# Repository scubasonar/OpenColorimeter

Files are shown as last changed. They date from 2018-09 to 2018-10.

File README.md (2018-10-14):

# OpenColorimeter
Open source colorimeter project by Matthew Valancy for California State University Monterey Bay Capstone.

Hardware and software for measuring light passing through a sample vial.

*Mechanical design in FreeCAD v0.17
*Electrical design in KiCAD 5.0.0
*Software written with Arduino IDE 1.8.7

### See Wiki for more information.

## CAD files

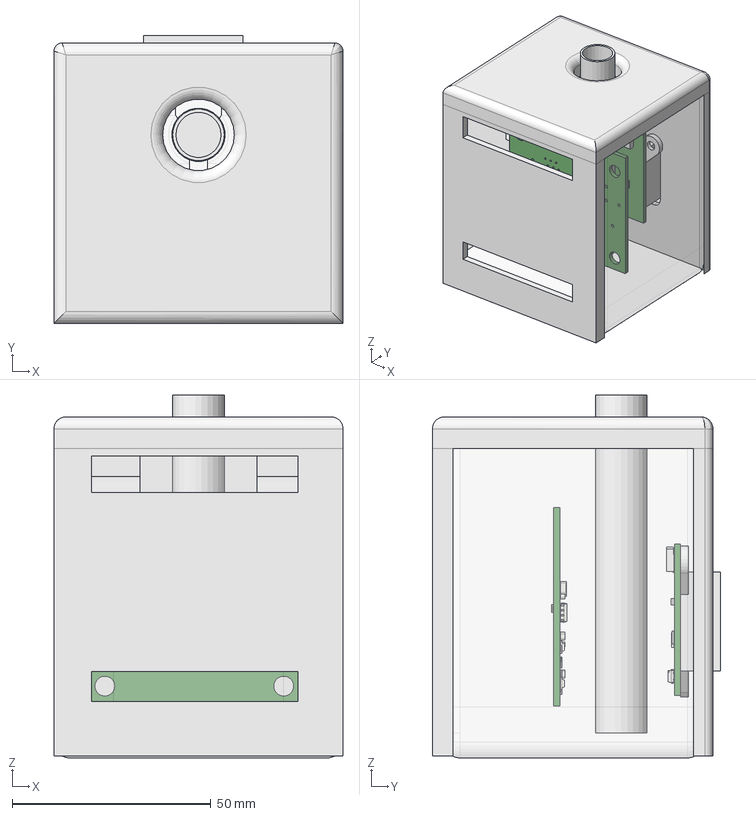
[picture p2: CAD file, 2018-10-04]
Mechanical/Colorimeter.fcstd
72.7 x 72.5 x 91.3 mm
API_Test_Tube_5mlMarked
Housing_Main
ATS-CPX-137-C1-R0_FUSED
Housing_Cover

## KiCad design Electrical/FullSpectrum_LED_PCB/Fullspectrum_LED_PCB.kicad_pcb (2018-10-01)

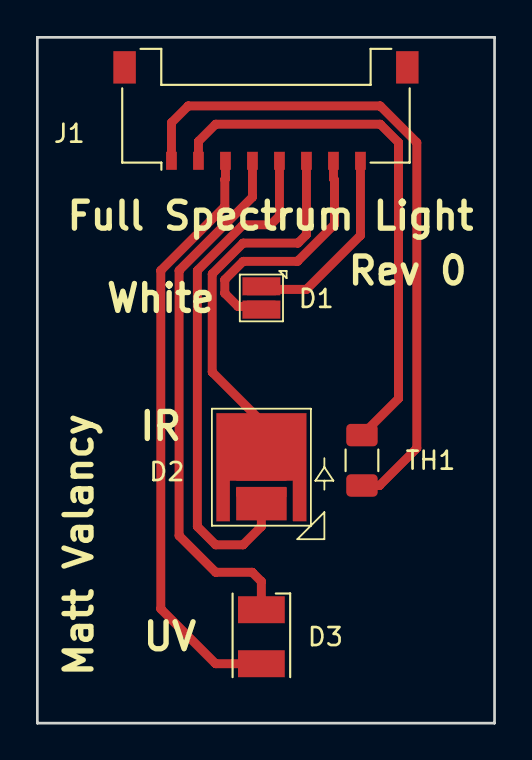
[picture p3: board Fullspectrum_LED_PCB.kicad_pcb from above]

Board: 2 copper layers, 25.4 x 38.1 mm, 5 parts (0 on the bottom side), 8 nets.

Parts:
D1: White_LED; LED_Cree_XQ-E
D2: IR_LED; LED_Oslon_SFH_4735
D3: UV_LED; LED_PLCC-2
J1: Conn_01x08_Male; Molex_Pico-Lock_504050-0891_1x08-1MP_P1.50mm_Horizontal
TH1: Thermistor_NTC; R_1206_3216Metric

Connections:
unnamed: D1.1, J1.8
unnamed: D1.2, J1.7
unnamed: D2.1, J1.6
unnamed: D2.2, J1.5
unnamed: D3.1, J1.4
unnamed: D3.2, J1.3
unnamed: J1.1, TH1.1
unnamed: J1.2, TH1.2

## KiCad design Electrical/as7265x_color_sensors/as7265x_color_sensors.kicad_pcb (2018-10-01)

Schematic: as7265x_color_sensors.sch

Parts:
C1, C2, C3: 100nF; C_0805_2012Metric
C4, C5, C6: 10uF; C_0805_2012Metric
C7: 1uF; C_0805_2012Metric
D1, D2, D3, D4, D5, D6: LED_Small; LED_1206_3216Metric
F1, F2: Polyfuse; C_1206_3216Metric
J1: Conn_01x06_Male; Harwin_M20-89006xx_1x06_P2.54mm_Horizontal
J2, J3: RJ12; RJ12_Amphenol_54601
R1, R2, R3, R4, R5, R6: R_Small; R_0805_2012Metric
R7: 10k; R_0805_2012Metric
R8: DNP; R_0805_2012Metric
R9: 0R; R_0805_2012Metric
R10, R11, R12, R13: 10K; R_0805_2012Metric
TP1, TP2, TP3, TP4, TP5, TP6, TP8, TP9, TP10, TP11, TP12, TP13, TP14, TP15, TP17: TestPoint; Pin_D1.0mm_L10.0mm_LooseFit
TVS1, TVS2, TVS3: SP3012-06UTG; uDFN-14_3.5x1.35x0.5mm
U1: AS72651; LGA-20_4.5mm_4.7mm_2.5mm
U2: AS72652; LGA-20_4.5mm_4.7mm_2.5mm
U3: AS72653; LGA-20_4.5mm_4.7mm_2.5mm
U4: AT25SF041; SOIC-8_3.9x4.9mm_P1.27mm

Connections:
+3V3: C1.1, C2.1, C3.1, C4.1, C5.1, C6.1, C7.1, F1.1, F2.1, J1.4, R1.2, R2.2, R3.2, R4.2, R5.2, R6.2, R7.1, R8.2, TP1.1, TP14.1, TVS1.13, TVS2.13, TVS3.9, U1.14, U1.17, U2.14, U2.17, U3.14, U3.17, U4.3 (~WP), U4.7 (~HOLD), U4.8 (VCC)
/CTS: J1.5, TP15.1, TVS3.8
/DTR: J1.1, TP11.1, TVS3.13
/LED1: D1.1, J3.2, TVS2.8, U1.18
/LED2: D2.1, J3.3, TVS2.9, U1.15
/LED3: D3.1, J3.4, TVS2.11, U2.18
/LED4: D4.1, J3.5, TVS2.12, U2.15
/LED5: D5.1, J2.2, TVS1.8, U3.18
/LED6: D6.1, J2.3, TVS1.9, U3.15
/RXI: J1.3, J2.4, TP13.1, TVS1.11, TVS3.11, U1.11
/TXO: J1.2, J2.5, TP12.1, TVS1.12, TVS3.12, U1.12
/~INT: TP17.1, U1.13
GND: C1.2, C2.2, C3.2, C4.2, C5.2, C6.2, C7.2, J1.6, J2.1, J3.1, R9.1, R10.1, R11.1, R12.1, R13.1, TVS1.10, TVS2.10, TVS3.10, U1.16, U2.16, U3.16, U4.4 (GND)
unnamed: D1.2, R1.1
unnamed: D2.2, R2.1
unnamed: D3.2, R3.1
unnamed: D4.2, R4.1
unnamed: D5.2, R5.1
unnamed: D6.2, R6.1
unnamed: F1.2, J2.6
unnamed: F2.2, J3.6
unnamed: R7.2, U1.2, U2.2, U3.2
unnamed: R8.1, R9.2, TP5.1, U1.8
unnamed: R10.2, U3.5
unnamed: R11.2, U2.5
unnamed: R12.2, U3.7
unnamed: R13.2, U2.7
unnamed: TP2.1, U1.10, U2.10, U3.10
unnamed: TP3.1, U1.9, U2.9, U3.9
unnamed: TP4.1, U1.7
unnamed: TP6.1, U1.6, U4.1 (~CS)
unnamed: TP8.1, U1.5, U4.2 (MISO)
unnamed: TP9.1, U1.4, U4.5 (MOSI)
unnamed: TP10.1, U1.3, U4.6 (SCK)

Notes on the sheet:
Connector for SparkFun FTDI Basic Breakout - 3.3V
LED port
Comm port
Firmware
Master Color Sensor
Expansion Color Sensor
FTDI Plug

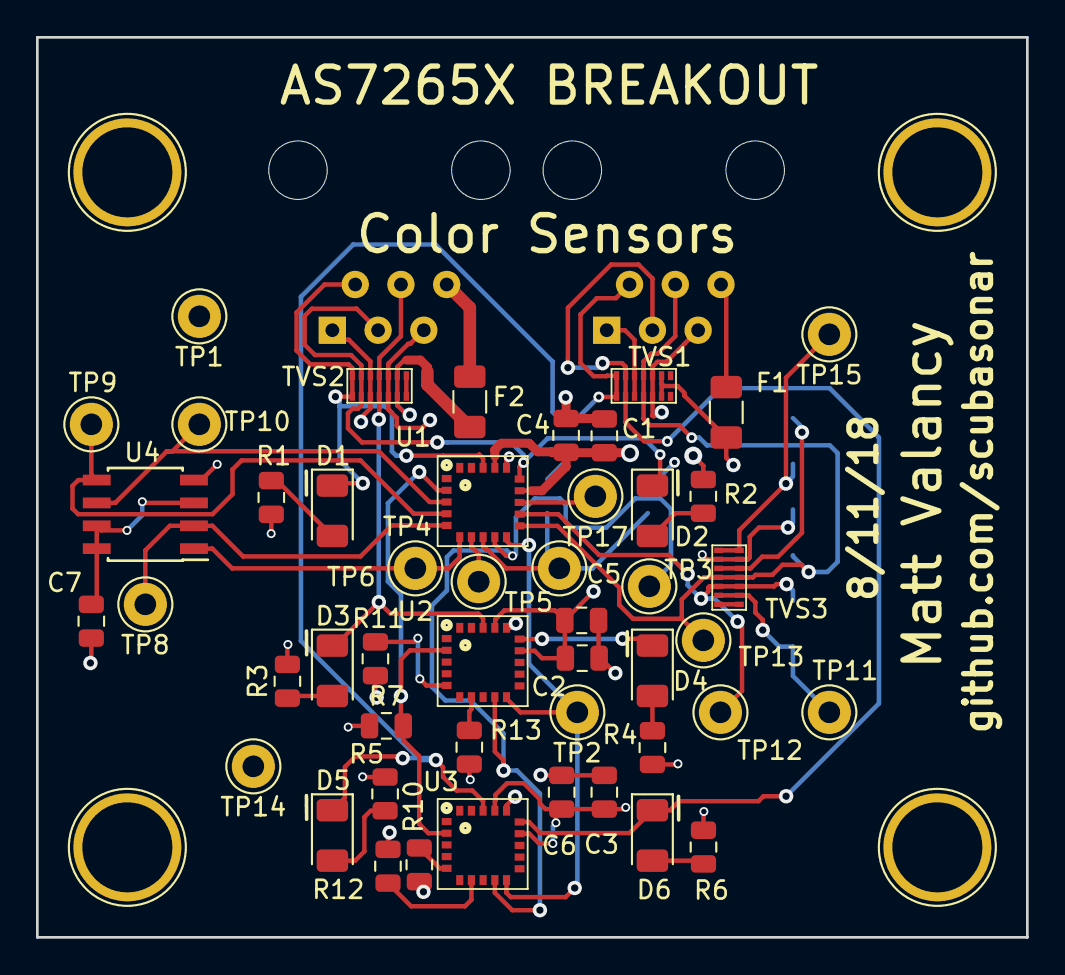
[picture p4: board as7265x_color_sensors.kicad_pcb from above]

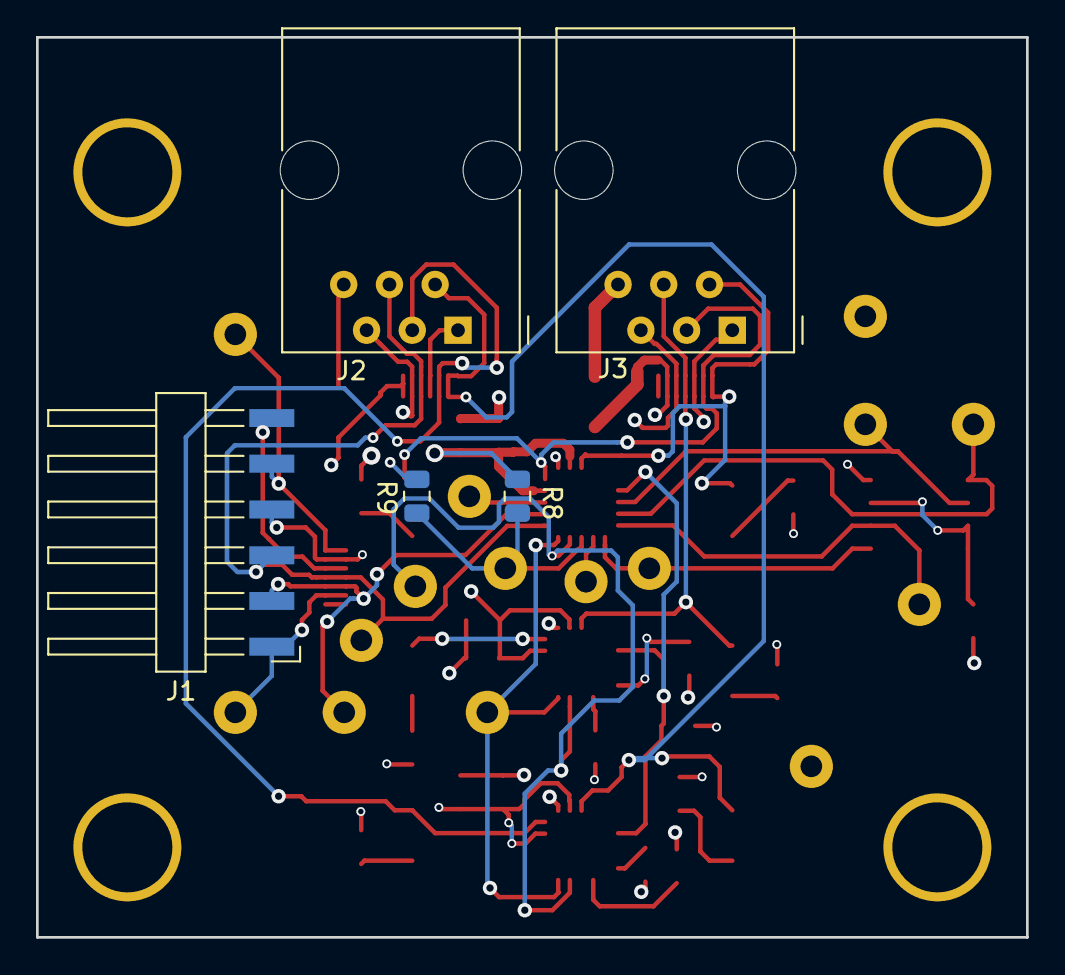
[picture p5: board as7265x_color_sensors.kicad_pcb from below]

Board: 4 copper layers, 55.0 x 50.0 mm, 53 parts (5 on the bottom side), 34 nets.

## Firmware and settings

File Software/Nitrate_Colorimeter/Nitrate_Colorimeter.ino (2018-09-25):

#include <ESP8266WiFi.h>
#include <Wire.h>
#include <PubSubClient.h>

#define wifi_ssid ""
#define wifi_password ""

#define mqtt_server "192.168.1.17"
#define mqtt_user ""
#define mqtt_password ""

//!!!!! channel E responds most to nitrate testing

// ------------- command parser
const byte numChars = 128;
char receivedChars[numChars];
char tempChars[numChars];        // temporary array for use when parsing
bool dataGood = false;

      // variables to hold the parsed data
char messageFromPC[numChars] = {0};
int integerFromPC = 0;
float floatFromPC = 0.0;

const byte SENSOR_COUNT = 18;
unsigned long int lightValues[SENSOR_COUNT];

boolean newData = false;
// -------------- command parser

WiFiClient espClient;
PubSubClient client(espClient);
char message_buff[100];   // used for MQTT subscription
const int AVG_SAMPLES = 20;
const int PIN_LED = 0;
long lastMsg = 0; 


void setup_wifi() {
  delay(10);
  // We start by connecting to a WiFi network
  Serial.println();
  Serial.print("Connecting to ");
  Serial.println(wifi_ssid);

  WiFi.begin(wifi_ssid, wifi_password);

  while (WiFi.status() != WL_CONNECTED) {
    delay(500);
    Serial.print(".");
  }

  Serial.println("");
  Serial.println("WiFi connected");
  Serial.println("IP address: ");
  Serial.println(WiFi.localIP());
}

void setup() {
  pinMode(PIN_LED, OUTPUT);
  analogWriteFreq(300);
  analogWrite(PIN_LED, 0);
  
  Serial.begin(115200);
  setup_wifi();
  client.setServer(mqtt_server, 1883);

  
}

void reconnect() {
  // Loop until we're reconnected
  while (!client.connected()) {
    Serial.print("Attempting MQTT connection...");
    // Attempt to connect
    // If you do not want to use a username and password, change next line to
    // if (client.connect("ESP8266Client")) {
    if (client.connect("ESP8266Client", mqtt_user, mqtt_password)) {
      Serial.println("connected");
    } else {
      Serial.print("failed, rc=");
      Serial.print(client.state());
      Serial.println(" try again in 5 seconds");
      // Wait 5 seconds before retrying
      delay(5000);
    }
  }
}

// receive color data from UART port 
// The color data is a string of comma separated values. 
void recvColorData() {
    static byte ndx = 0;
    char endMarker = '\n';
    char rc;
    int commaCnt = 0;
    while (Serial.available() > 0 && newData == false) {
        rc = Serial.read();
        //Serial.print(rc);
          if (rc != endMarker) {
              receivedChars[ndx] = rc;
              ndx++;
              if(rc == ',')
                commaCnt++;
              if (ndx >= numChars) {
                  ndx = numChars - 1;
              }
          }
          else {
              receivedChars[ndx] = '\0'; // terminate the string
               receivedChars[127] = '\0'; // terminate the string
              ndx = 0;
              if(commaCnt == 17) // only send good data...
                newData = true;
              //Serial.print("rx: ");
              //Serial.println(receivedChars);
          }
        }
}

// parse serial commands for color color data  !!!! PROBLEM IS IN HERE
int parseData() {      // split the data into its parts
  char * strStart;
  char * strEnd;
  int i = 0;
  int commaCnt = 0;


 // ------- DATA VALIDATION START
  if(strcmp("ERROR", tempChars) == 0)
  {
    //Serial.println("received error");
    return -1;
  }
  
  Serial.println(tempChars);
    
  for(i = 0; i < SENSOR_COUNT; i++)
    lightValues[i] == 0;

  for(i = 0; i < numChars; i++)
  {   
      if(tempChars[i] == '\0')
        break;
      else
        if(tempChars[i] == ',')
          commaCnt++;
      
      dataGood = false;
      if(commaCnt == SENSOR_COUNT - 1)
      {
        dataGood = true;
      }
  }

  // ------- DATA VALIDATION END
  
  // ------- DATA PARSING 
  strStart = tempChars;
  for(i = 0; i < SENSOR_COUNT; i++)
   {
    lightValues[i] = strtoul(strStart, &strEnd, 0);
    strStart = strEnd;
    if(strStart[0] == ',')
      strStart++;
    if(strStart[0] == ' ')
      strStart++;
   }

    return 0;
}

void loop() {
  unsigned long value = 0;
  
  if (!client.connected()) {
    reconnect();
  }
  client.loop();
  analogWrite(PIN_LED, 100);
  Serial.println("ATINTTIME=250\r\n");
  delay(500);
  Serial.println("ATGAIN=1\r\n");
  delay(5000);
  int i = 0;
  int k = 10;

  // collect and average 5 samples for the color we are intested in
  // in this case it is lightValues[17] which is the one that responds
  // to the nitrate solution
  for(i = 0; i < 5; k= 10)
  {
      client.loop();
      delay(250);
      Serial.print("ATDATA\r\n");
      delay(900);
      recvColorData();
      
      while((newData == false) && k > 0)
      {
        recvColorData();
        k--;
        delay(100);
      }
      if (newData == true) {
       
        newData = false;
        strcpy(tempChars, receivedChars);  // this temporary copy is necessary to protect the original data
                                         //   because strtok() used in parseData() replaces the commas with \0
        if(!parseData())
        {
           value += lightValues[17];
           i++;
           client.publish("debug", String(i).c_str(), true); 
           //publishColors();
        }
        
      }
      
  }

  client.publish("debug", String(i).c_str(), true); 
  value /= 5;
  
  publishColors();

  client.publish("debug", "Cooldown mode", true); 
  analogWrite(PIN_LED, 0);
  for(i=0; i < 20; i++)
  {
    delay(100);
    client.loop();
  }
}

// public eash sensor color to it's own MQTT topic, making subscribing easy
void publishColors()
{
   client.publish("sensor/color_r", String(lightValues[0]).c_str(), true);
   client.publish("sensor/color_s", String(lightValues[1]).c_str(), true);
   client.publish("sensor/color_t", String(lightValues[2]).c_str(), true);
   client.publish("sensor/color_u", String(lightValues[3]).c_str(), true);
   client.publish("sensor/color_v", String(lightValues[4]).c_str(), true);
   client.publish("sensor/color_w", String(lightValues[5]).c_str(), true);
   client.publish("sensor/color_j", String(lightValues[6]).c_str(), true);
   client.publish("sensor/color_i", String(lightValues[7]).c_str(), true);
   client.publish("sensor/color_g", String(lightValues[8]).c_str(), true);
   client.publish("sensor/color_h", String(lightValues[9]).c_str(), true);
   client.publish("sensor/color_k", String(lightValues[10]).c_str(), true);
   client.publish("sensor/color_l", String(lightValues[11]).c_str(), true);
   client.publish("sensor/color_d", String(lightValues[12]).c_str(), true);
   client.publish("sensor/color_c", String(lightValues[13]).c_str(), true);
   client.publish("sensor/color_a", String(lightValues[14]).c_str(), true);
   client.publish("sensor/color_b", String(lightValues[15]).c_str(), true);
   client.publish("sensor/color_e", String(lightValues[16]).c_str(), true);
   client.publish("sensor/color_f", String(lightValues[17]).c_str(), true);
}

void showParsedData() {
  for(int i = 0; i < SENSOR_COUNT; i++)
  {
      Serial.print(lightValues[i]);
      Serial.print(" ");    
  }
  Serial.println("\r\n");

}

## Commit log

2018-07-29 start of project
    [Carousel_TopLevel.SLDASM]
2018-07-30 added some basic CAD concept
    [Carousel_TopLevel.SLDASM, testTube_API_5mL.SLDPRT]
2018-09-25 added new files
    [Carousel_TopLevel.SLDASM, Colorimeter.fcstd, testTube_API_5mL.SLDPRT]
2018-09-27 designed new light source for spectrometry with full range of light 400nm-1050nm
    [Colorimeter.fcstd, Fullspectrum_LED_PCB.kicad_pcb, Fullspectrum_LED_PCB.sch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]
2018-10-01 worked on mechanical housing, printing new version overnight
    [Colorimeter.fcstd, Fullspectrum_LED_PCB.kicad_pcb]
2018-10-01 added color sensor board
    [as7265x_color_sensors.kicad_pcb, as7265x_color_sensors.sch]
2018-10-01 moved light pcb out of unnecessary folder
    [Fullspectrum_LED_PCB.kicad_pcb, Fullspectrum_LED_PCB.sch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]
2018-10-02 shifted sensor board position for light alignment and tightened up the test tube holder
    [Colorimeter.fcstd]
2018-10-04 made first version of lid, printing test part now
    [Colorimeter.fcstd]
